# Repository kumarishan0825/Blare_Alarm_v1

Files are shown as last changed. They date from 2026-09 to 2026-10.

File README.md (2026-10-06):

# Blare_Alarm_v1 - ESP32-C3 Hardware Project

Welcome to the complete repository for the Blare Alarm project. This project a fully custom hardware layout driven by an ESP32-C3 microcontroller, custom enclosure CAD models, and production-ready manufacturing files.

---

## Project Showcase

### Overall Clock Design
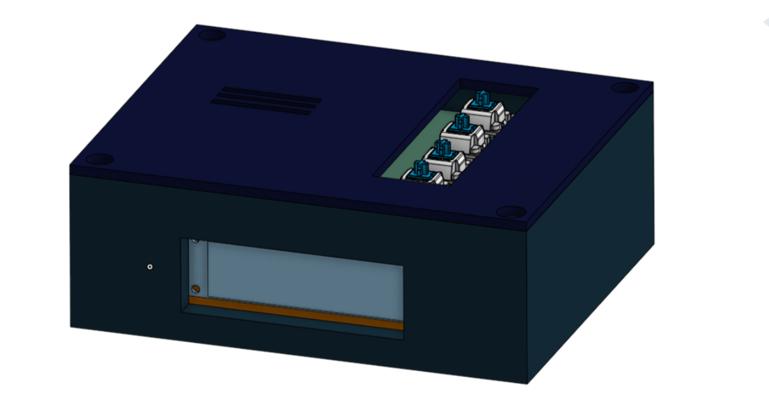
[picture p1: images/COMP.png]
Overall Clock


### Circuit Schematic
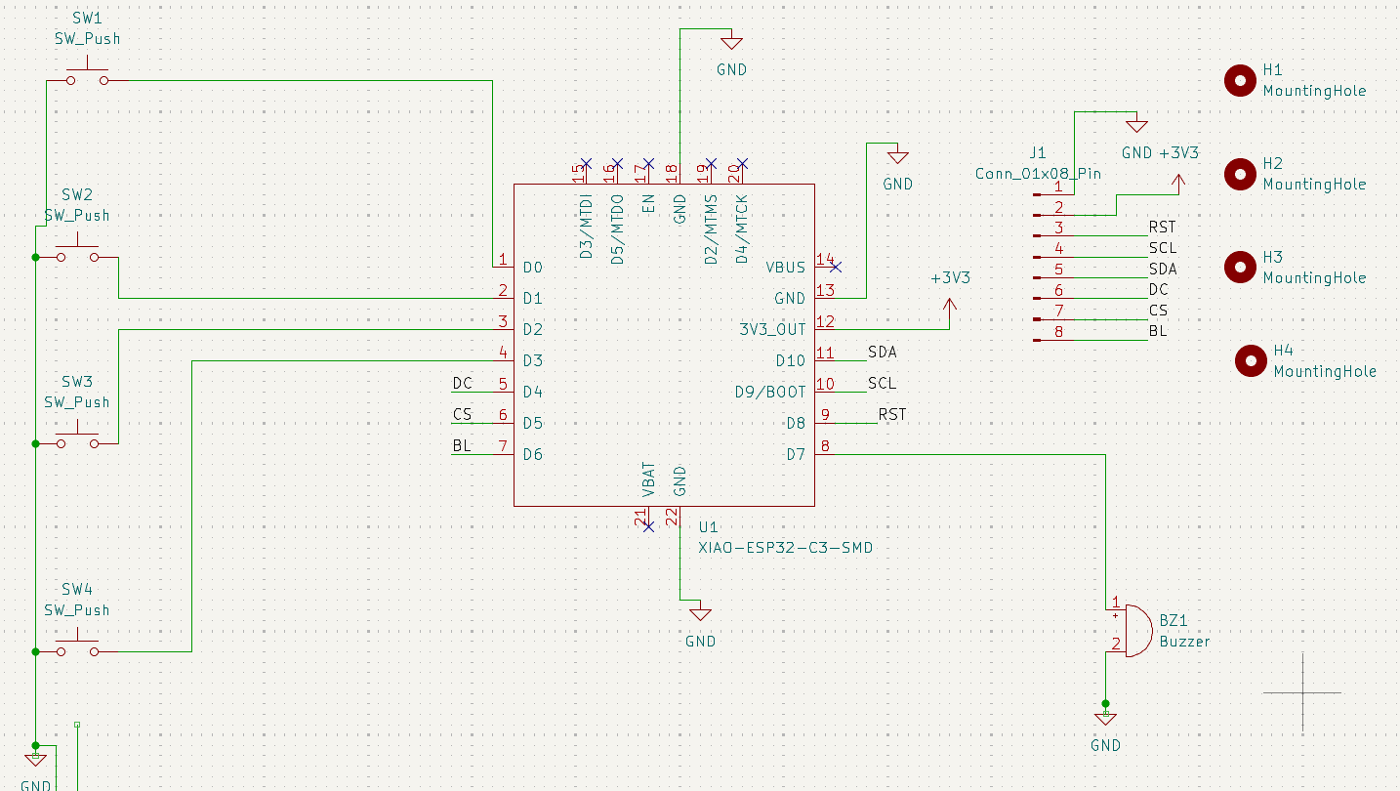
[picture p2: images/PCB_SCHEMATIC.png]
Schematic Design


### PCB Board Layout
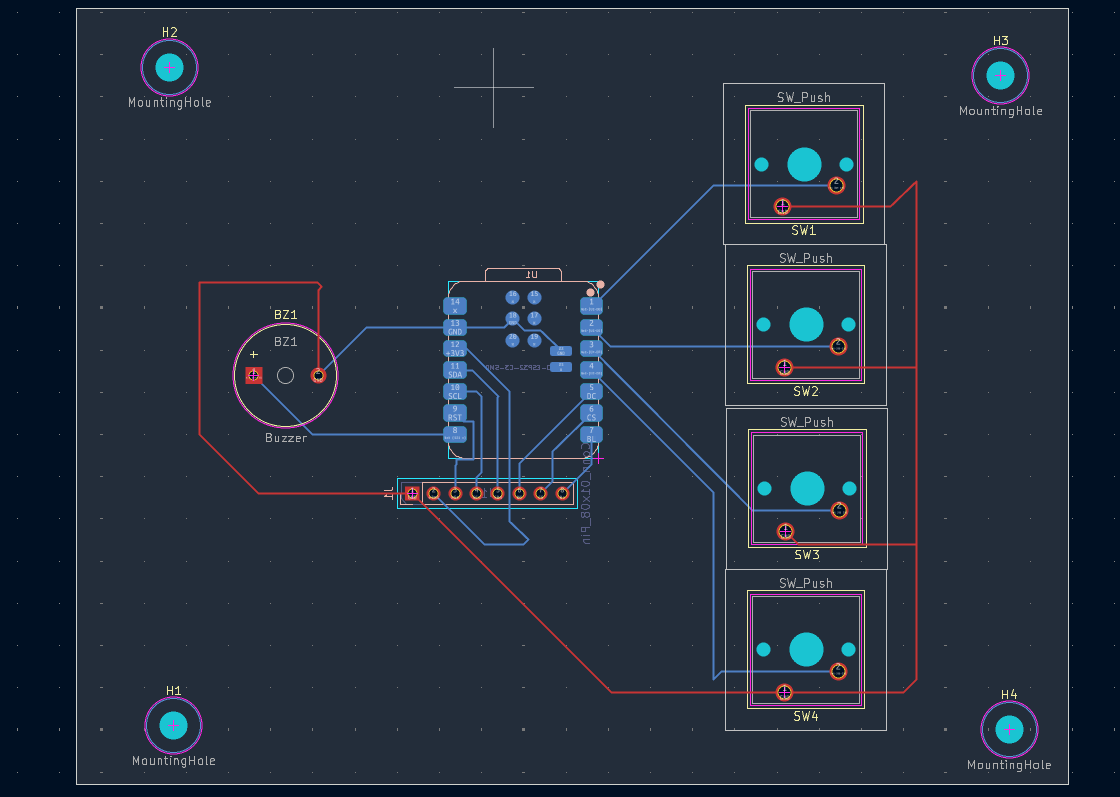
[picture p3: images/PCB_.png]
PCB Layout


### Enclosure & Integration Fit
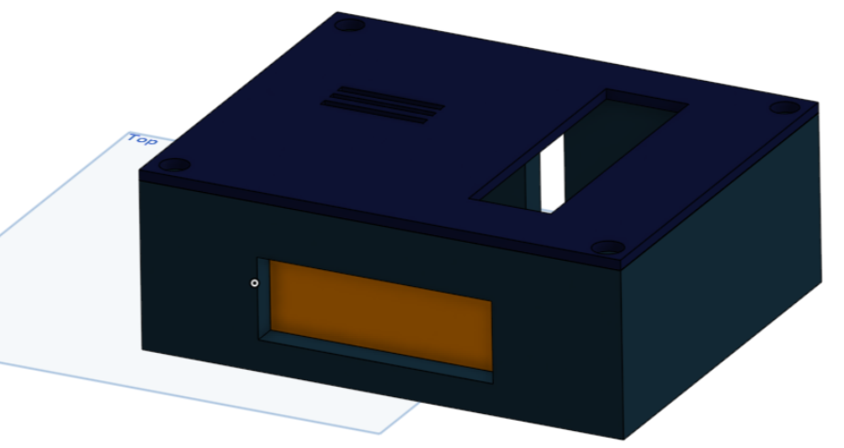
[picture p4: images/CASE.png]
Case Integration


---

## Bill of Materials (BOM)

| Component Description | Quantity | Package /Type | Notes |
| :--- | :--- | :--- | :--- |
| ESP32-C3 Microcontroller | 1 | Custom Footprint | Main system processor |
| Mechanical Keyboard Switches | 4 | 2-Pin Through-Hole (PTH) | Input keys for interface |
| Matching Keycaps | 4 | Plastic Caps | Fitted onto mechanical switches |
| 3.3V Buzzer | 1 | Through-Hole (PTH) | Mounted on PCB for alarm audio |
| 2.25in TFT Display | 1 | Screen Module | Main clock screen interface |
| Custom Enclosure Case | 1 | 3D Printed (STEP Model) | Physical shell designed in Onshape |

## Repository Organization
1)CAD/: Core 3D design models.
2)Firmware/: Arduino application source code.
3)PCB/: Portable KiCad source designs with project related footprint libraries.
4)Production/: Factory-ready "gerbers.zip" manufacturing archive.

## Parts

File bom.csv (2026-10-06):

Component Description | Quantity | Package / Type | Price(per piece) | Reference Link
Seeed Studio XIAO ESP32C3 | 1 | Development Board Module | $4.99 USD / ₹420-₹500 INR | https://wiki.seeedstudio.com/XIAO_ESP32C3_Getting_Started/
Mechanical Keyboard Switches | 4 | 2-Pin Through-Hole (PTH) | $0.22 USD / ₹20-₹25 INR per switch | https://www.thecosmicbyte.com/product/gateron-mechanical-switches-compatible-with-cosmic-byte-hot-swappable-keyboards-qty-1pc/
Matching Keycaps | 4 | Plastic Caps | $6.95 USD per 1 pack(12pcs) / ₹669.91 INR per 1 pack (12pcs) | https://www.adafruit.com/product/5068
3.3V Audio Buzzer | 1 | Through-Hole (PTH) | $0.95 USD / ₹91.57 INR | https://www.adafruit.com/product/1536
2.25in TFT Display | 1 | Screen Module | $2.65 USD / ₹255.43 INR | https://www.buydisplay.com/2-25-inch-tft-serial-spi-76x284-lcd-display-module-w-st7789p3
Custom Enclosure Case | 1 | 3D Printed (STEP Model) | $2 to $6 USD (~30g-50g) / ₹150-₹500 INR (~30g-50g) | https://github.com/kumarishan0825/Blare_Alarm_v1/blob/main/CAD/Case_integration.step
Total amount: |  |  | ~$17.76 - $21.76 USD/ ₹1606.91 - ₹2041.91 INR

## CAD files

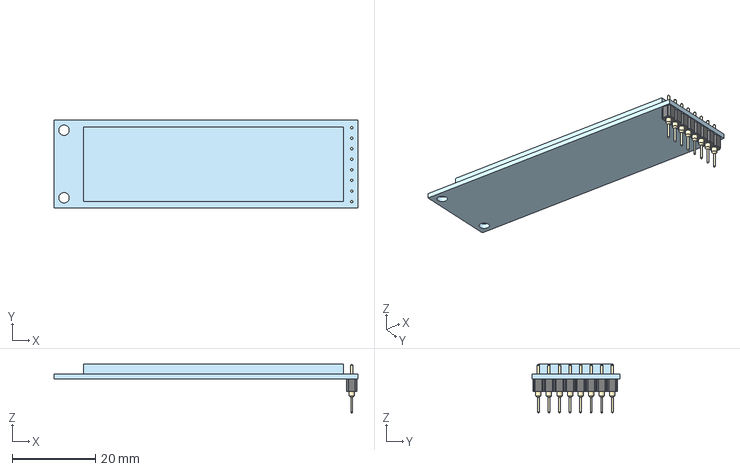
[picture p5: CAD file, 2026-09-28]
CAD/Display with pins.step
73.2 x 21.1 x 11.8 mm
8 pin header v1_1 x 9

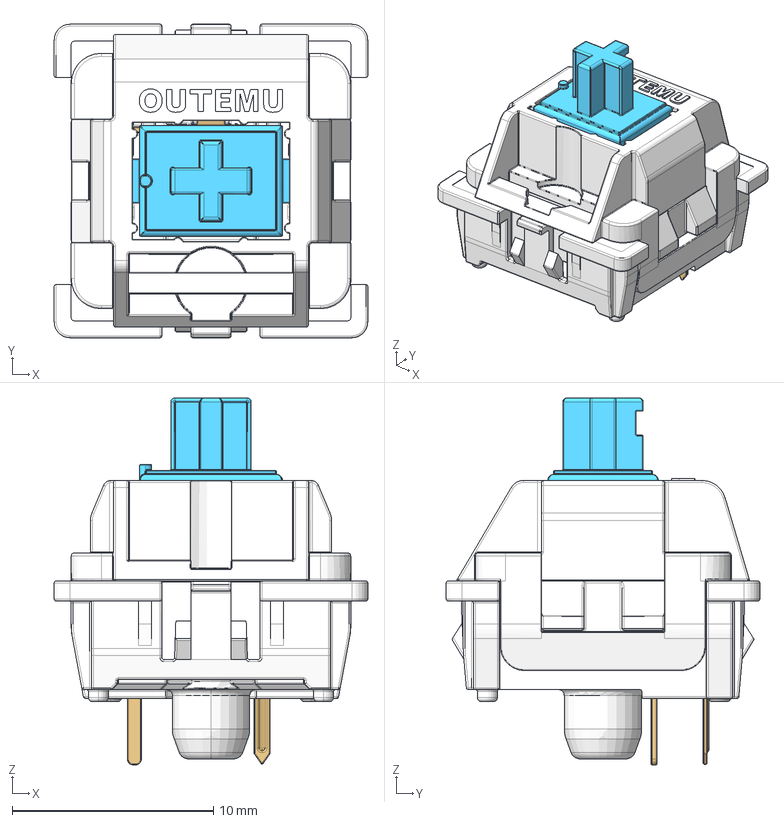
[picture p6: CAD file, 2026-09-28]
CAD/mxstp.stp
15.6 x 15.6 x 18.2 mm
BOTT
PIN
SPRIN
CLICK
RET
TOP

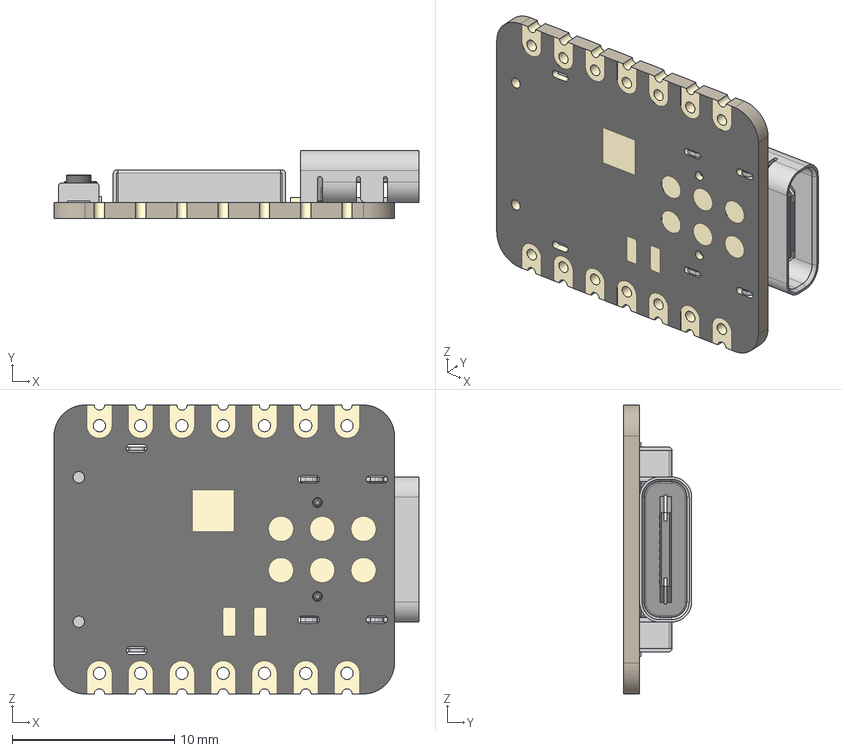
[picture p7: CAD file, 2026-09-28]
CAD/Seeed Studio XIAO-ESP32-C3.step
22.5 x 4.21 x 17.8 mm
BOSS-EXTRUDE14_8_
BOSS-EXTRUDE7_4_
BOSS-EXTRUDE7_3_
BOSS-EXTRUDE14_4_
BOSS-EXTRUDE14_2_
BOSS-EXTRUDE14_11_
BOSS-EXTRUDE7_7_
BOSS-EXTRUDE14_9_
BOSS-EXTRUDE14_3_
BOSS-EXTRUDE14_7_
MIRROR2
BOSS-EXTRUDE14_5_
BOSS-EXTRUDE14_12_
BOSS-EXTRUDE7_8_
BOSS-EXTRUDE7_1_
BOSS-EXTRUDE14_10_
BOSS-EXTRUDE7_9_
BOSS-EXTRUDE14_6_
BOSS-EXTRUDE14_1_
BOSS-EXTRUDE7_6_
BOSS-EXTRUDE7_2_
CUT-EXTRUDE5
BOSS-EXTRUDE7_5_
U.FL Connector v1
Button (1) x 2
Shield

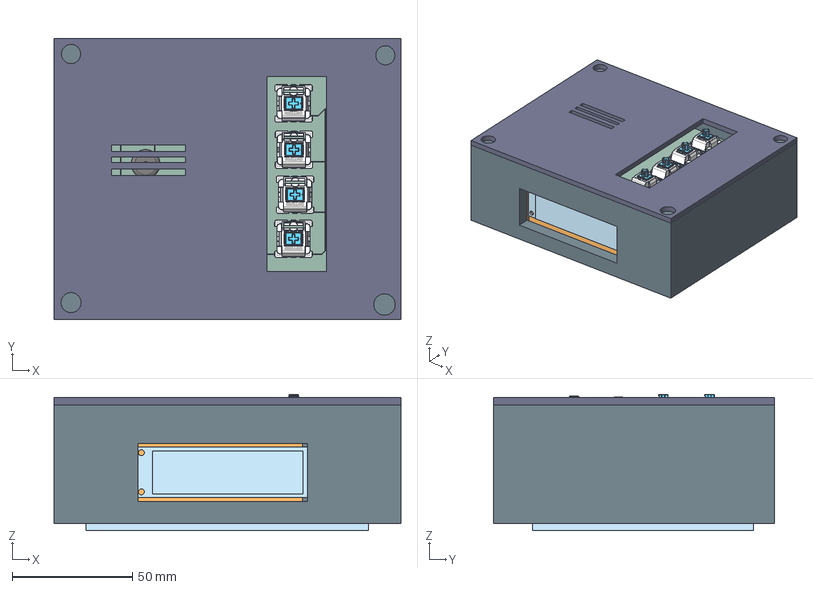
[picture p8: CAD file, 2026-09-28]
CAD/Case_integration.step
144.2 x 116.6 x 56.7 mm
BLA4D4E_pad x 76
PinSocket_1x08_P2.54mm_Vertical
BLA4D4E_copper x 16
BOSS-EXTRUDE7_8_:1__Körper1
BOSS-EXTRUDE7_1_:1__Körper1
RET x 4
BOSS-EXTRUDE7_6_:1__Körper1
BOSS-EXTRUDE14_4_:1__Körper1
BOSS-EXTRUDE14_8_:1__Körper1
BOSS-EXTRUDE7_7_:1__Körper1
PIN x 8
SPRIN x 4
CLICK x 4
BOSS-EXTRUDE7_5_:1__Körper1
BOTT x 4
PCB
BOSS-EXTRUDE14_9_:1__Körper1
TOP x 4
BOSS-EXTRUDE14_7_:1__Körper1
BOSS-EXTRUDE14_10_:1__Körper1
BOSS-EXTRUDE14_6_:1__Körper1
8 pin header v1_1__8 pin header v1_1 x 9
BOSS-EXTRUDE14_2_:1__Körper1
U.FL Connector v1:1__Körper1
BOSS-EXTRUDE7_4_:1__Körper1
Button (1):1__Körper1
Shield:1__Körper1
BOSS-EXTRUDE7_3_:1__Körper1
BOSS-EXTRUDE14_12_:1__Körper1
BOSS-EXTRUDE14_11_:1__Körper1
Button (1):1__Körper1_1
U.FL Connector v1:1__Körper3
BOSS-EXTRUDE7_9_:1__Körper1
BLA4D4E_PCB
U.FL Connector v1:1__Körper2
BOSS-EXTRUDE14_1_:1__Körper1
Part 1__Part 1
BOSS-EXTRUDE14_5_:1__Körper1
BOSS-EXTRUDE14_3_:1__Körper1
CHAMFER9:1__Körper1
Buzzer_12x95RM76
CUT-EXTRUDE5:1__Körper1
BOSS-EXTRUDE7_2_:1__Körper1
MIRROR2:1__Körper1

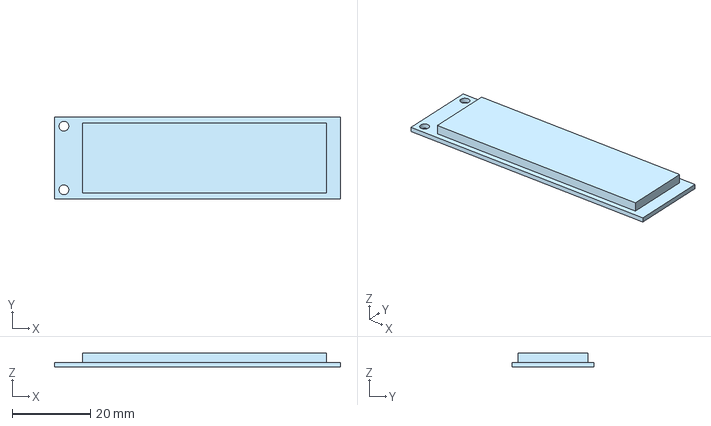
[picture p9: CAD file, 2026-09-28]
CAD/2.25in TFT Display.step
73.2 x 21.1 x 3.56 mm

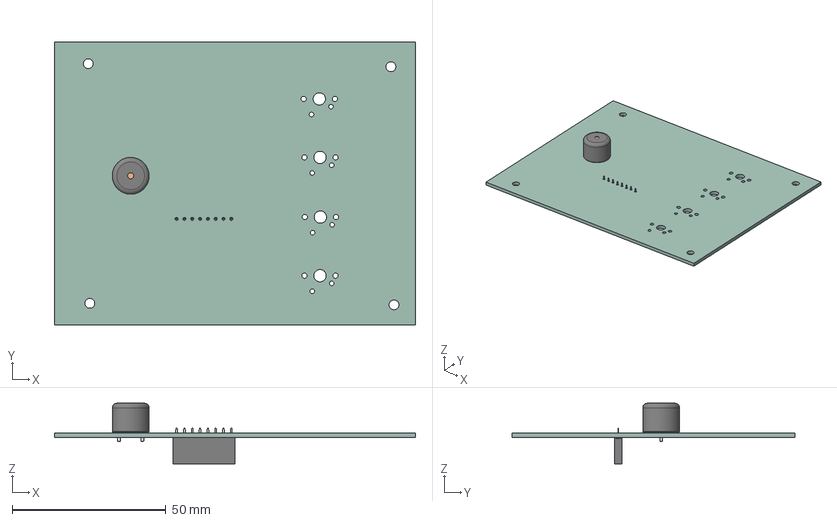
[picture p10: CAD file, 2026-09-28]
CAD/PCB_BLARE_ALARM.step
117.5 x 92.0 x 19.7 mm
Buzzer_12x95RM76
PinSocket_1x08_P2.54mm_Vertical
BLADD3_PCB

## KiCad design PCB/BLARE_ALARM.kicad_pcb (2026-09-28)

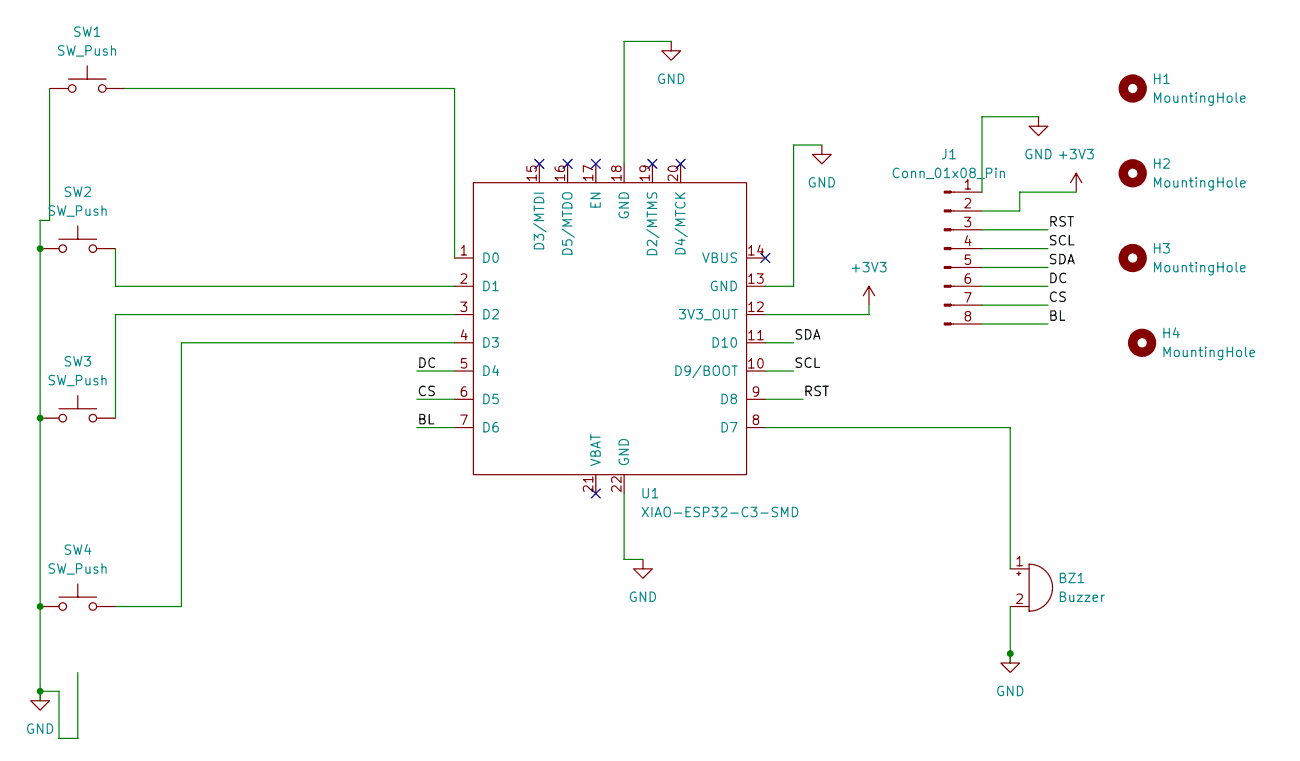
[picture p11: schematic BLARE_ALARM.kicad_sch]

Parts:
BZ1: Buzzer; Buzzer_12x9.5RM7.6
H1, H2, H3, H4: MountingHole; MountingHole_3.2mm_M3
J1: Conn_01x08_Pin; PinSocket_1x08_P2.54mm_Vertical
SW1, SW2, SW3, SW4: SW_Push; SW_Cherry_MX_1.00u_PCB
U1: XIAO-ESP32-C3-SMD

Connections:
+3V3: J1.2, U1.12 (3V3_OUT)
/BL: J1.8, U1.7 (D6)
/CS: J1.7, U1.6 (D5)
/DC: J1.6, U1.5 (D4)
/RST: J1.3, U1.9 (D8)
/SCL: J1.4, U1.10 (D9/BOOT)
/SDA: J1.5, U1.11 (D10)
GND: BZ1.2 (-), J1.1, SW1.1, SW2.1, SW3.1, SW4.1, U1.13 (GND), U1.18 (GND), U1.22 (GND)
unnamed: BZ1.1 (+), U1.8 (D7)
unnamed: SW1.2, U1.1 (D0)
unnamed: SW2.2, U1.2 (D1)
unnamed: SW3.2, U1.3 (D2)
unnamed: SW4.2, U1.4 (D3)

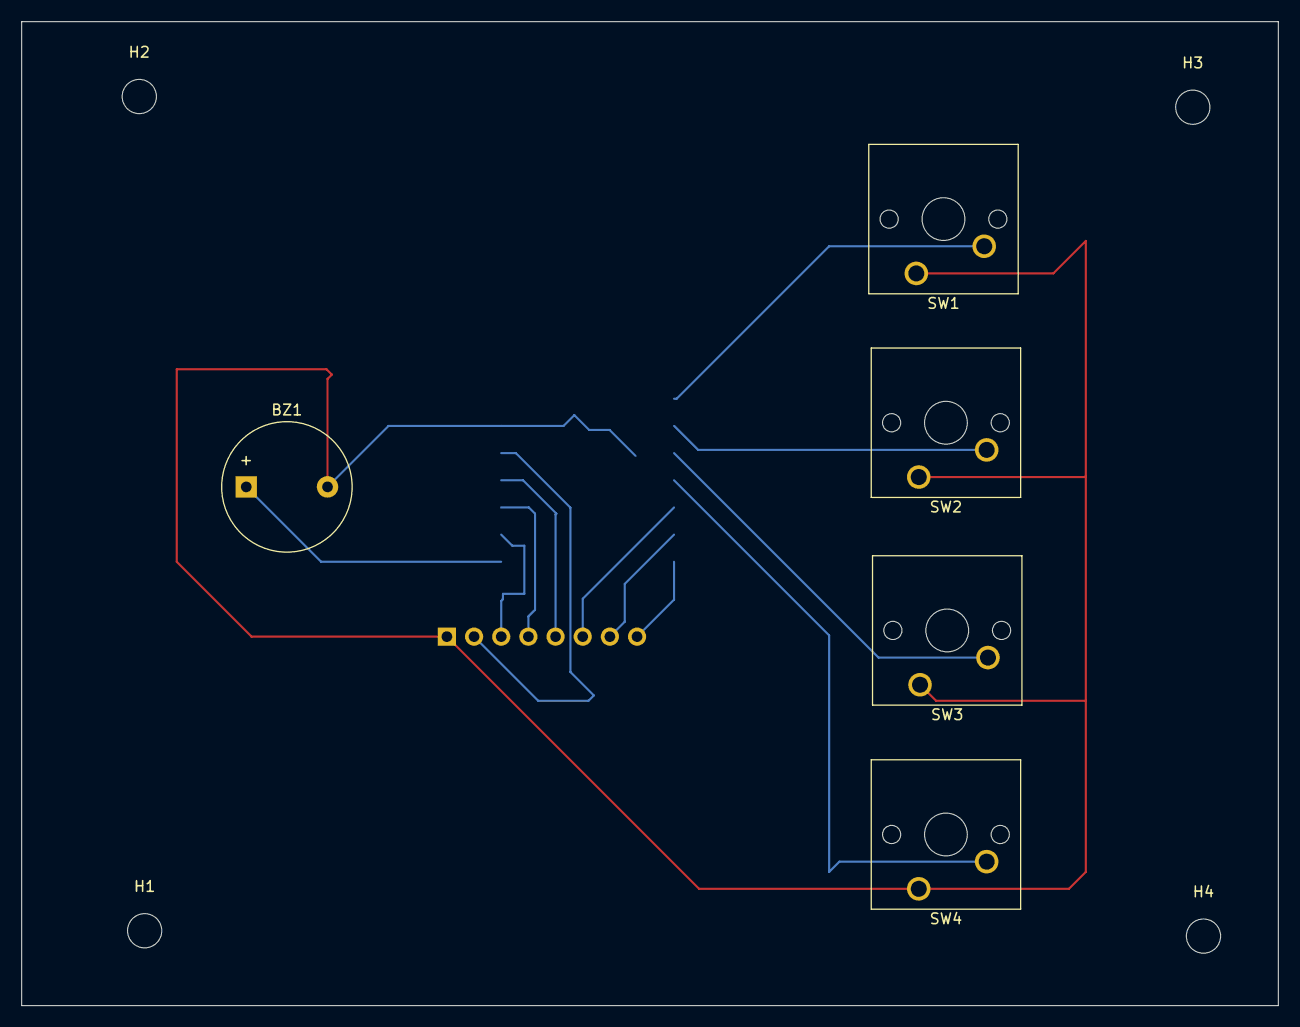
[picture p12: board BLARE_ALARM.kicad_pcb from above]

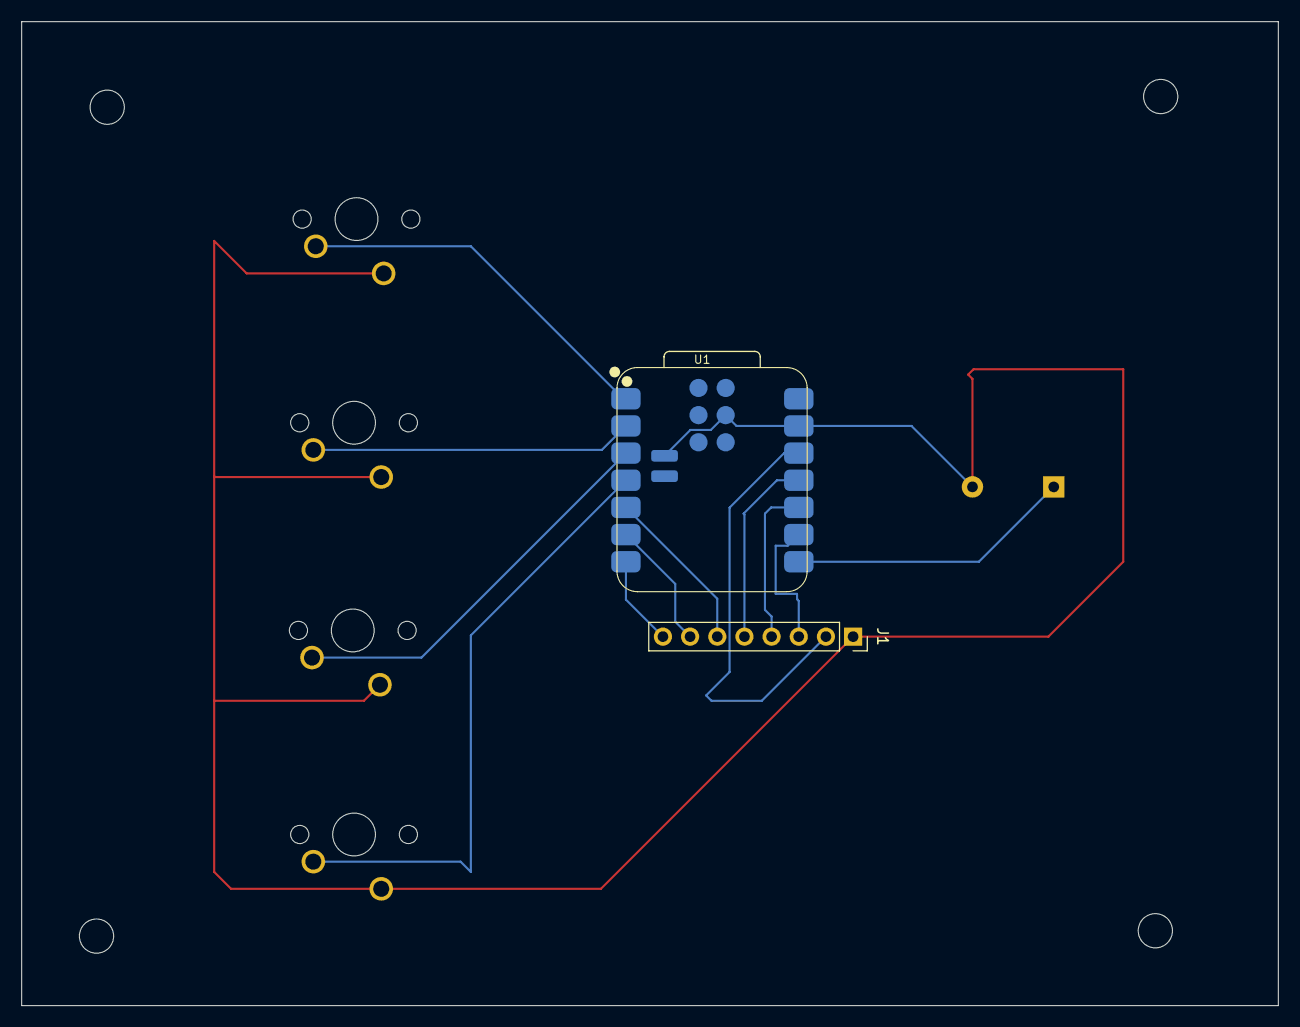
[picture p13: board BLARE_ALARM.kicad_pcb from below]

Board: 2 copper layers, 117.5 x 92.0 mm, 11 parts (2 on the bottom side), 13 nets.

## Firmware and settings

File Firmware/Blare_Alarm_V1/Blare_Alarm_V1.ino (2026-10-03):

#include <Adafruit_GFX.h>
#include <Adafruit_ST7789.h>
#include <SPI.h>
#define TFT_SCLK 9    
#define TFT_MOSI 10   
#define TFT_RST  8    
#define TFT_DC   6    
#define TFT_CS   7    
#define TFT_BL   21   
#define BUZZER_PIN 20   
#define BTN1_PIN   2    
#define BTN2_PIN   3    
#define BTN3_PIN   4    
#define BTN4_PIN   5    
#define BUZZER_PASSIVE 0   
#define START_HOUR 7
#define START_MIN  42

class MyST7789 : public Adafruit_ST7789 {
public:
  MyST7789(int8_t cs, int8_t dc, int8_t mosi, int8_t sclk, int8_t rst)
    : Adafruit_ST7789(cs, dc, mosi, sclk, rst) {}

  void setOffsets(uint8_t col, uint8_t row) {
    _colstart = _colstart2 = col;
    _rowstart = _rowstart2 = row;
  }
};

MyST7789 tft(TFT_CS, TFT_DC, TFT_MOSI, TFT_SCLK, TFT_RST);

int hourNow = START_HOUR, minNow = START_MIN, secNow = 0;
int alarmH = 8, alarmM = 0;
unsigned long lastTick = 0;

enum Mode { CLOCK_MODE, SET_HOURS, SET_MINUTES, RINGING };
Mode mode = CLOCK_MODE;

bool alarmHandled = false;   
bool needRedraw = true;

const uint8_t btnPins[4] = { BTN1_PIN, BTN2_PIN, BTN3_PIN, BTN4_PIN };
bool lastReading[4]  = { false, false, false, false };
bool stableState[4]  = { false, false, false, false };
unsigned long lastChange[4] = { 0, 0, 0, 0 };
const unsigned long DEBOUNCE_MS = 30;

bool buttonPressed(int i) {
  bool reading = (digitalRead(btnPins[i]) == LOW);
  if (reading != lastReading[i]) {
    lastReading[i] = reading;
    lastChange[i] = millis();
  }
  if (millis() - lastChange[i] > DEBOUNCE_MS && reading != stableState[i]) {
    stableState[i] = reading;
    if (stableState[i]) return true;
  }
  return false;
}

void setBuzzer(bool on) {
  static bool current = false;
  if (on == current) return;
  current = on;
#if BUZZER_PASSIVE
  if (on) tone(BUZZER_PIN, 2000);
  else noTone(BUZZER_PIN);
#else
  digitalWrite(BUZZER_PIN, on ? HIGH : LOW);
#endif
}

void updateClock() {
  while (millis() - lastTick >= 1000) {
    lastTick += 1000;
    secNow++;
    if (secNow >= 60) {
      secNow = 0;
      minNow++;
      if (minNow >= 60) {
        minNow = 0;
        hourNow = (hourNow + 1) % 24;
      }
      if (mode == CLOCK_MODE) needRedraw = true;  
    }
  }
}

void print2(int n) {
  if (n < 10) tft.print('0');
  tft.print(n);
}
void drawTime(int x, int y, int size, int h, int m, uint16_t hCol, uint16_t mCol) {
  int cw = 6 * size;   
  tft.setTextSize(size);
  tft.setTextColor(hCol);
  tft.setCursor(x, y);
  print2(h);
  tft.setTextColor(ST77XX_WHITE);
  tft.setCursor(x + 2 * cw, y);
  tft.print(':');
  tft.setTextColor(mCol);
  tft.setCursor(x + 3 * cw, y);
  print2(m);
}

void drawScreen() {
  tft.fillScreen(ST77XX_BLACK);

  if (mode == CLOCK_MODE) {
    tft.setTextSize(1);
    tft.setTextColor(ST77XX_CYAN);
    tft.setCursor(2, 2);
    tft.print("BLARE");

    drawTime(67, 6, 5, hourNow, minNow, ST77XX_WHITE, ST77XX_WHITE);

    tft.setTextSize(2);
    tft.setTextColor(ST77XX_GREEN);
    tft.setCursor(76, 48);
    tft.print("Alarm ");
    print2(alarmH);
    tft.print(':');
    print2(alarmM);

    tft.setTextSize(1);
    tft.setTextColor(ST77XX_WHITE);
    tft.setCursor(76, 67);
    tft.print("[SET] [UP] [DOWN] [OK]");

  } else if (mode == SET_HOURS || mode == SET_MINUTES) {
    tft.setTextSize(2);
    tft.setTextColor(ST77XX_CYAN);
    tft.setCursor(88, 2);
    tft.print("SET ALARM");

    bool editingHours = (mode == SET_HOURS);
    drawTime(82, 22, 4, alarmH, alarmM,
             editingHours ? ST77XX_YELLOW : ST77XX_WHITE,
             editingHours ? ST77XX_WHITE : ST77XX_YELLOW);

    tft.setTextSize(2);
    tft.setTextColor(ST77XX_YELLOW);
    tft.setCursor(editingHours ? 106 : 100, 58);
    tft.print(editingHours ? "HOURS" : "MINUTES");

  } else if (mode == RINGING) {
    tft.setTextSize(3);
    tft.setTextColor(ST77XX_RED);
    tft.setCursor(88, 0);
    tft.print("ALARM!");

    drawTime(102, 28, 2, alarmH, alarmM, ST77XX_WHITE, ST77XX_WHITE);

    tft.setTextSize(2);
    tft.setTextColor(ST77XX_YELLOW);
    tft.setCursor(88, 52);
    tft.print("PRESS OK");
  }
}

void handleButtons() {
  bool b1 = buttonPressed(0);  
  bool b2 = buttonPressed(1);  
  bool b3 = buttonPressed(2);  
  bool b4 = buttonPressed(3);  

  if (mode == RINGING) {
    if (b4) {                  
      alarmHandled = true;
      mode = CLOCK_MODE;
      needRedraw = true;
    }
    return;
  }

  if (mode == CLOCK_MODE) {
    if (b1) {
      mode = SET_HOURS;
      needRedraw = true;
    }
    return;
  }

  if (b1) {                    
    mode = (mode == SET_HOURS) ? SET_MINUTES : SET_HOURS;
    needRedraw = true;
  }
  if (b2) {                    
    if (mode == SET_HOURS) alarmH = (alarmH + 1) % 24;
    else alarmM = (alarmM + 1) % 60;
    needRedraw = true;
  }
  if (b3) {                    
    if (mode == SET_HOURS) alarmH = (alarmH + 23) % 24;
    else alarmM = (alarmM + 59) % 60;
    needRedraw = true;
  }
  if (b4) {                   
    alarmHandled = false;
    mode = CLOCK_MODE;
    needRedraw = true;
  }
}

void checkAlarm() {
  if (minNow != alarmM || hourNow != alarmH) alarmHandled = false;

  if (mode == CLOCK_MODE && !alarmHandled &&
      hourNow == alarmH && minNow == alarmM) {
    mode = RINGING;
    needRedraw = true;
  }
}

void setup() {
  pinMode(TFT_BL, OUTPUT);
  digitalWrite(TFT_BL, LOW);

  tft.init(76, 284);
  tft.setOffsets(82, 18);
  tft.invertDisplay(false);
  tft.setRotation(1);

  for (int i = 0; i < 4; i++) pinMode(btnPins[i], INPUT_PULLUP);
  pinMode(BUZZER_PIN, OUTPUT);
  digitalWrite(BUZZER_PIN, LOW);
  lastTick = millis();
}

void loop() {
  updateClock();
  handleButtons();
  checkAlarm();

  if (mode == RINGING) setBuzzer((millis() / 250) % 2 == 0);
  else setBuzzer(false);

  if (needRedraw) {
    needRedraw = false;
    drawScreen();
  }
}

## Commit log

2026-09-28 Enhance README with project showcase and BOM
    Added project showcase images and bill of materials.
2026-10-03 Refactor button and buzzer definitions
    [Blare_Alarm_V1.ino]
2026-10-03 Format and clean up display pin definitions
2026-10-06 addition of bom.csv file
    [bom.csv]
2026-10-06 Modify bom.csv with updated component links
    Updated links for components and added new entries.
    [bom.csv]
2026-10-06 Update URL for Custom Enclosure Case in bom.csv
    [bom.csv]
2026-10-06 Update BOM to include price per piece
    Added price information for each component in the BOM.
    [bom.csv]
2026-10-06 Fix formatting of total amount line in bom.csv
    [bom.csv]
